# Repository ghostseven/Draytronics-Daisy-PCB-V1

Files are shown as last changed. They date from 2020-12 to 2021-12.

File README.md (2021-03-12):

# Draytronics-Daisy-PCB-V1

daisy  

An open source macro pad with rotary encoders and under glow, designed to be easily built with (mostly) through hole components. More info / kits / PCB designs available at https://www.draytronics.co.uk/daisy

\
daisypcb

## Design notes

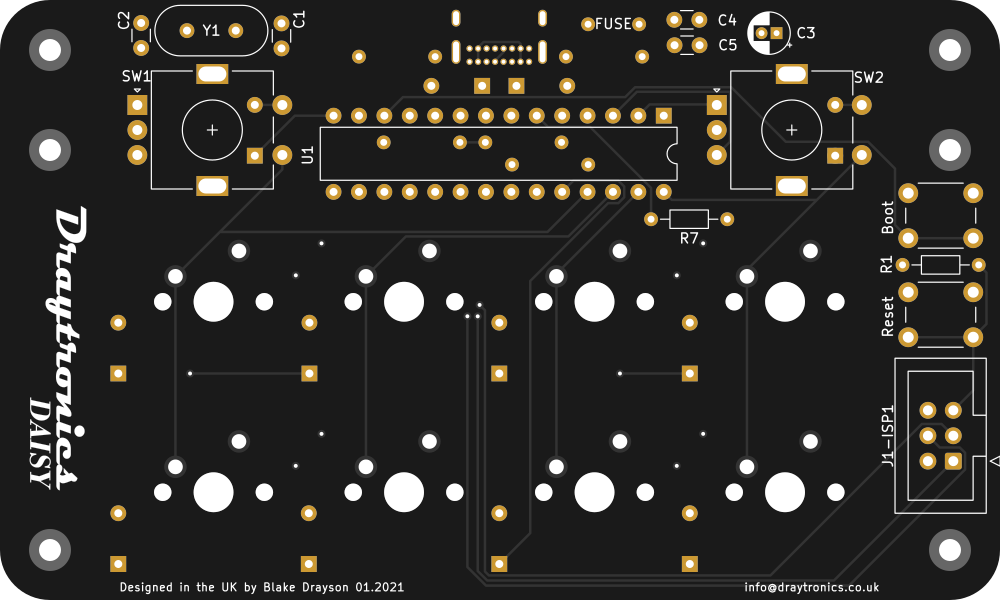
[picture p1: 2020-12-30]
Draytronics-Daisy-PCB-V1.png

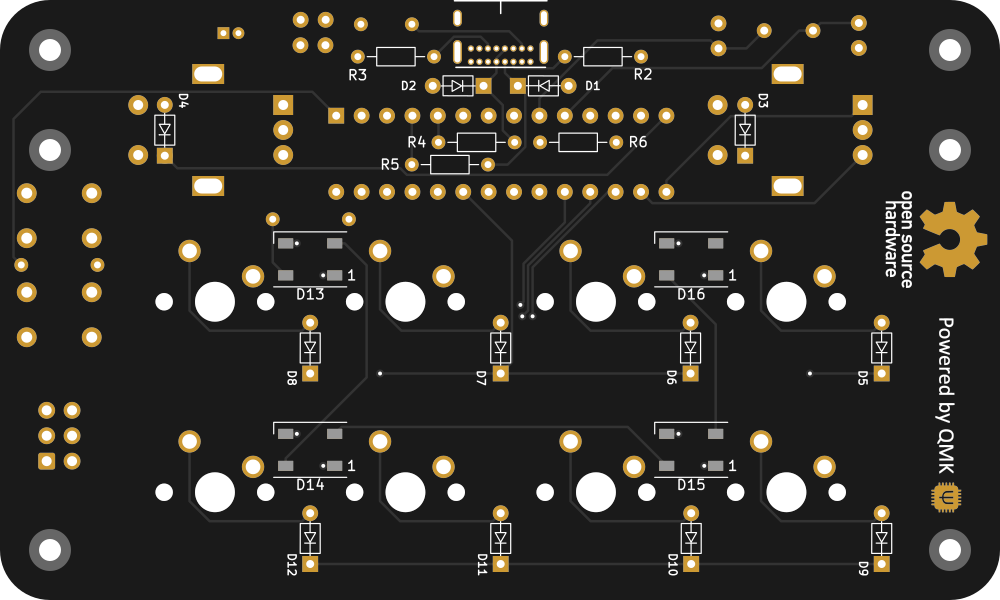
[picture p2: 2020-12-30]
Draytronics-Daisy-PCB-V1-bottom.png

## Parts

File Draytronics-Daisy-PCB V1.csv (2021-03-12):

Reference | Quantity | Value | Footprint | Datasheet
C1 C2 | 2 | 22pF | Capacitor_THT:C_Disc_D3.0mm_W1.6mm_P2.50mm | ~
C3 | 1 | 4.7uF | Capacitor_THT:CP_Radial_D4.0mm_P1.50mm | ~
C4 C5 | 2 | .1uF | Capacitor_THT:C_Disc_D3.0mm_W1.6mm_P2.50mm | ~
D13 D14 D15 D16 | 4 | WS2812B | LED_SMD:LED_WS2812B_PLCC4_5.0x5.0mm_P3.2mm | https://cdn-shop.adafruit.com/datasheets/WS2812B.pdf
D1 D2 | 2 | 3.6V | di-parts:D_DO-35_SOD27_P5.08mm_Horizontal | ~
D3 D4 D5 D6 D7 D8 D9 D10 D11 D12 | 10 | 1N4448W | di-parts:D_DO-35_SOD27_P5.08mm_Horizontal | https://www.vishay.com/docs/85722/1n4448w.pdf
F1 | 1 | 500ma | ctf-parts:polyfuse_5.1mm | ~
J1-ISP1 | 1 | AVR-ISP-6 | Connector_IDC:IDC-Header_2x03_P2.54mm_Vertical | ~
MX1 MX2 MX3 MX4 MX5 MX6 MX7 MX8 | 8 | MX-NoLED | MX_Only:MXOnly-1U-NoLED
R1 | 1 | 10k | Resistor_THT:R_Axial_DIN0204_L3.6mm_D1.6mm_P7.62mm_Horizontal | ~
R2 R3 | 2 | 5.1k | Resistor_THT:R_Axial_DIN0204_L3.6mm_D1.6mm_P7.62mm_Horizontal | ~
R4 R5 | 2 | 68R | Resistor_THT:R_Axial_DIN0204_L3.6mm_D1.6mm_P7.62mm_Horizontal | ~
R6 | 1 | 1.5k | Resistor_THT:R_Axial_DIN0204_L3.6mm_D1.6mm_P7.62mm_Horizontal | ~
R7 | 1 | 470R | Resistor_THT:R_Axial_DIN0204_L3.6mm_D1.6mm_P7.62mm_Horizontal | ~
SW1 SW2 | 2 | Rotary_Encoder_Switch | Rotary_Encoder:RotaryEncoder_Alps_EC11E-Switch_Vertical_H20mm | ~
SW3 | 1 | Reset | Button_Switch_THT:SW_PUSH_6mm
SW4 | 1 | Boot | Button_Switch_THT:SW_PUSH_6mm
U1 | 1 | ATmega328P-PU | Package_DIP:DIP-28_W7.62mm | http://ww1.microchip.com/downloads/en/DeviceDoc/ATmega328_P%20AVR%20MCU%20with%20picoPower%20Technology%20Data%20Sheet%2040001984A.pdf
USB1 | 1 | USB_C_Receptacle_USB2.0 | Type-C:USB_C_GCT_USB4085 | https://www.usb.org/sites/default/files/documents/usb_type-c.zip
Y1 | 1 | 16Mhz | Crystal:Crystal_HC49-U_Vertical | ~

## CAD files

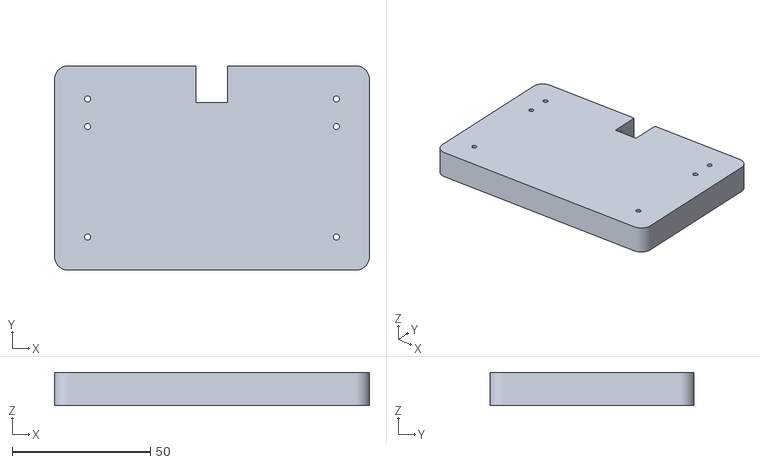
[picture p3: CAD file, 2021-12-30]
3d-printer-files/Draytronics-Daisy-PCB V1 - High Profile Case v1.stl
114.0 x 74.0 x 12.0

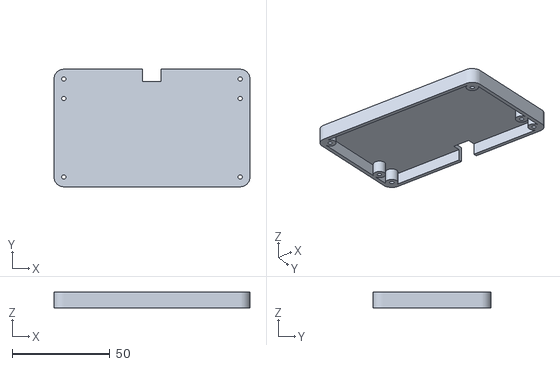
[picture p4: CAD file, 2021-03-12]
3d-printer-files/Draytronics-Daisy-PCB V1 - Bottom Case v6.stl
100.0 x 60.0 x 8.00

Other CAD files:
3d-printer-files/Draytronics-Daisy-PCB V1 - Bottom Case v6.f3d
3d-printer-files/Draytronics-Daisy-PCB V1 - High Profile Case v1.f3d

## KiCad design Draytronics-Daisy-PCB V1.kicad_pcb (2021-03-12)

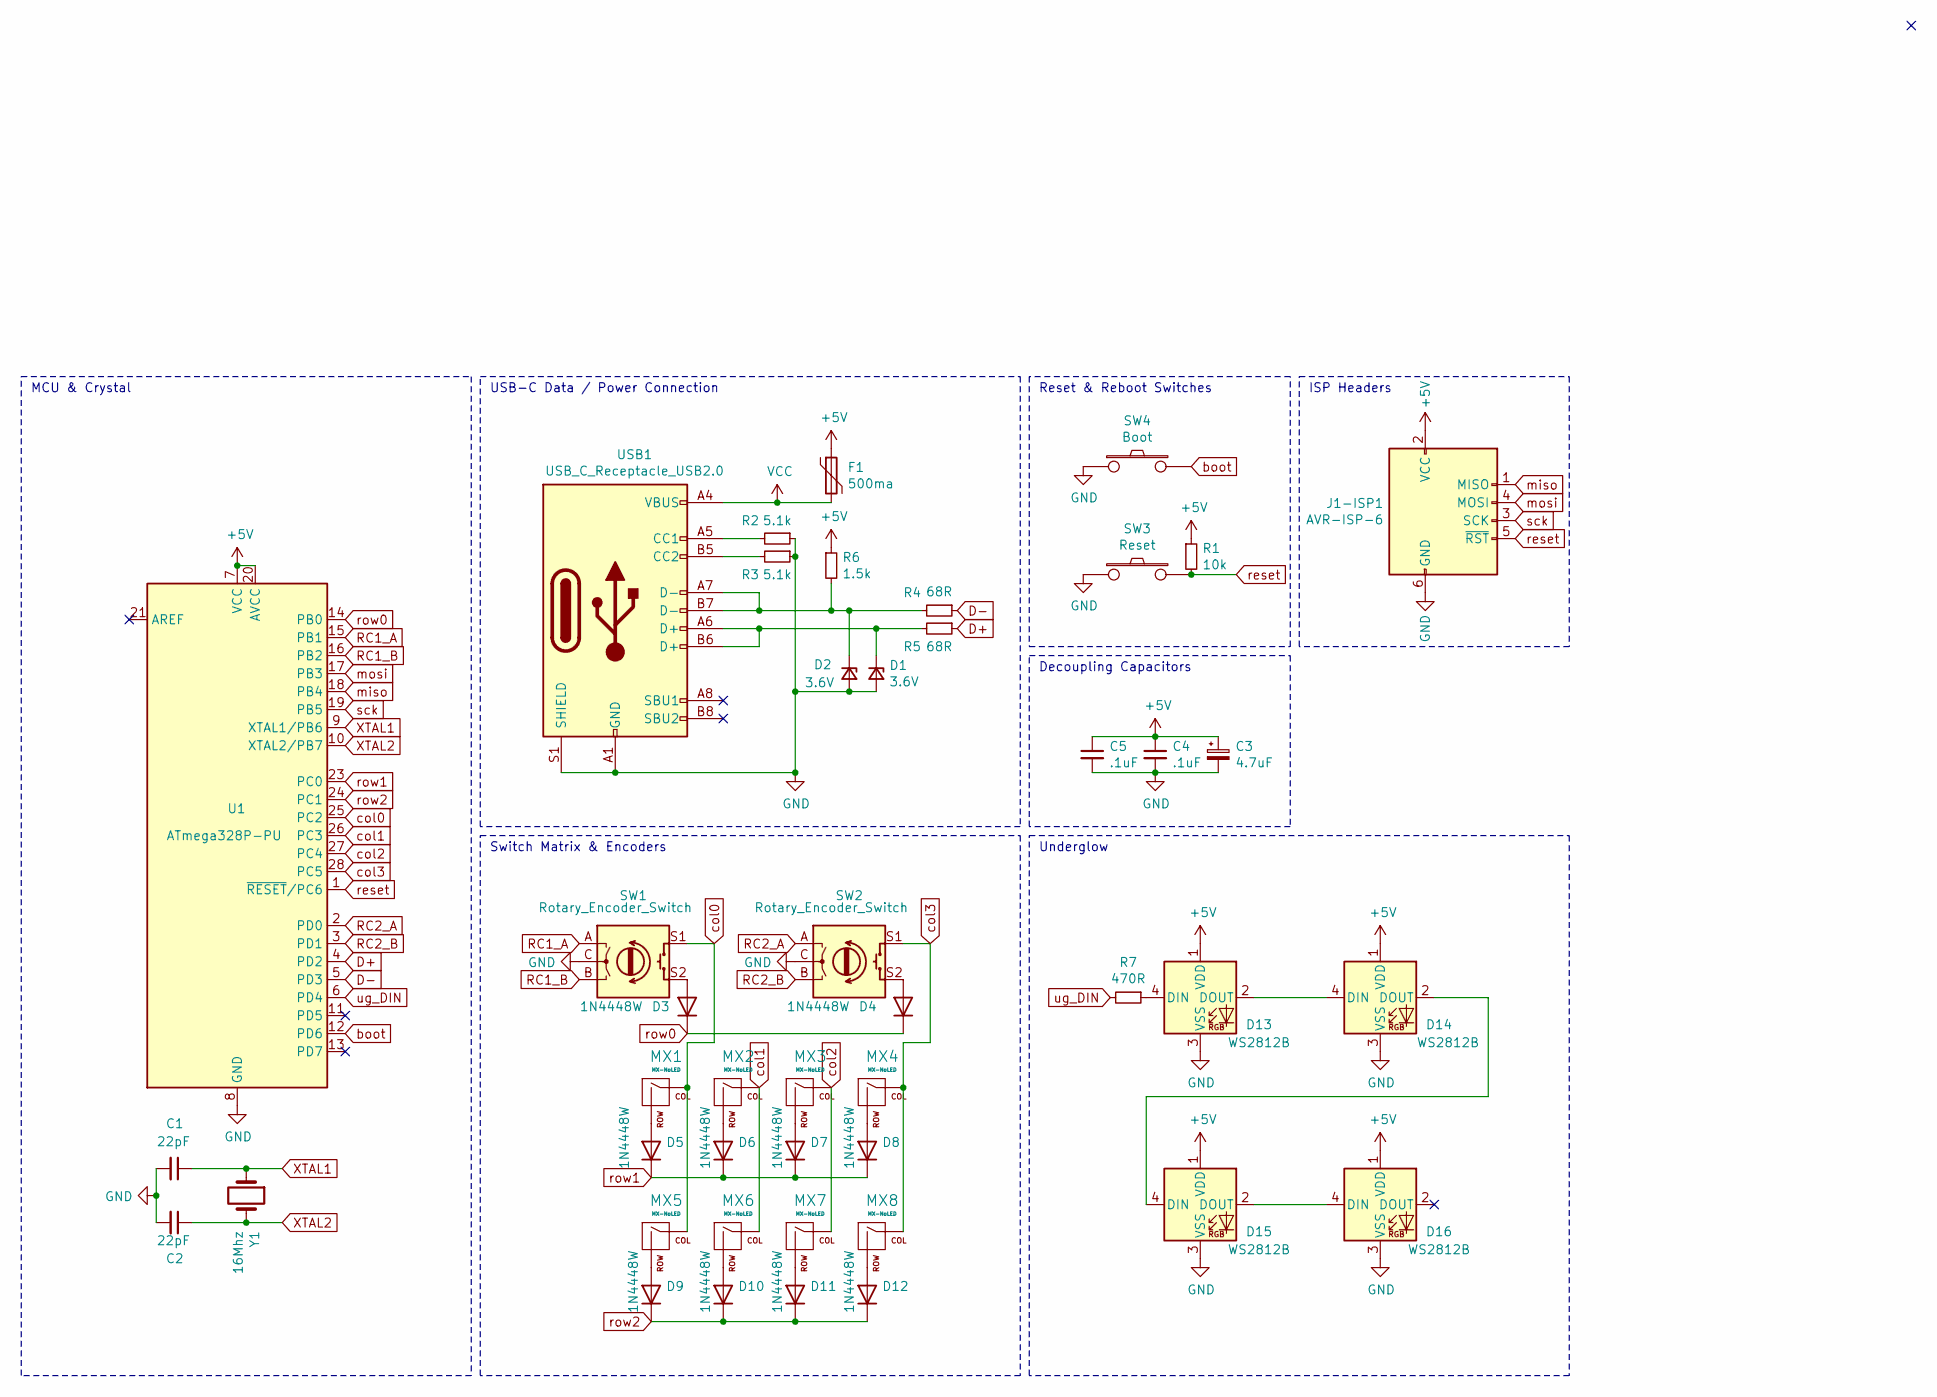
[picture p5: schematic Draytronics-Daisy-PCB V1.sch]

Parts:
C1, C2: 22pF; C_Disc_D3.0mm_W1.6mm_P2.50mm
C3: 4.7uF; CP_Radial_D4.0mm_P1.50mm
C4, C5: .1uF; C_Disc_D3.0mm_W1.6mm_P2.50mm
D1, D2: 3.6V; D_DO-35_SOD27_P5.08mm_Horizontal
D3, D4, D5, D6, D7, D8, D9, D10, D11, D12: 1N4448W; D_DO-35_SOD27_P5.08mm_Horizontal
D13, D14, D15, D16: WS2812B; LED_WS2812B_PLCC4_5.0x5.0mm_P3.2mm
F1: 500ma; polyfuse_5.1mm
J1-ISP1: AVR-ISP-6; IDC-Header_2x03_P2.54mm_Vertical
MX1, MX2, MX3, MX4, MX5, MX6, MX7, MX8: MX-NoLED; MXOnly-1U-NoLED
R1: 10k; R_Axial_DIN0204_L3.6mm_D1.6mm_P7.62mm_Horizontal
R2, R3: 5.1k; R_Axial_DIN0204_L3.6mm_D1.6mm_P7.62mm_Horizontal
R4, R5: 68R; R_Axial_DIN0204_L3.6mm_D1.6mm_P7.62mm_Horizontal
R6: 1.5k; R_Axial_DIN0204_L3.6mm_D1.6mm_P7.62mm_Horizontal
R7: 470R; R_Axial_DIN0204_L3.6mm_D1.6mm_P7.62mm_Horizontal
SW1, SW2: Rotary_Encoder_Switch; RotaryEncoder_Alps_EC11E-Switch_Vertical_H20mm
SW3: Reset; SW_PUSH_6mm
SW4: Boot; SW_PUSH_6mm
U1: ATmega328P-PU; DIP-28_W7.62mm
USB1: USB_C_Receptacle_USB2.0; USB_C_GCT_USB4085
Y1: 16Mhz; Crystal_HC49-U_Vertical

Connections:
+5V: C3.1, C4.1, C5.1, D13.1 (VDD), D14.1 (VDD), D15.1 (VDD), D16.1 (VDD), F1.1, J1-ISP1.2 (VCC), R1.1, R6.1, U1.7 (VCC), U1.20 (AVCC)
D+: R5.1, U1.4 (PD2)
D-: R4.1, U1.5 (PD3)
GND: C1.2, C2.2, C3.2, C4.2, C5.2, D1.2 (A), D2.2 (A), D13.3 (VSS), D14.3 (VSS), D15.3 (VSS), D16.3 (VSS), J1-ISP1.6 (GND), R2.1, R3.1, SW1.C, SW2.C, SW3.1, SW4.1, U1.8 (GND), U1.22 (GND), USB1.A1 (GND), USB1.A12 (GND), USB1.B1 (GND), USB1.B12 (GND), USB1.S1 (SHIELD)
unnamed: D1.1 (K), R5.2, USB1.A6 (D+), USB1.B6 (D+)
unnamed: D2.1 (K), R4.2, R6.2, USB1.A7 (D-), USB1.B7 (D-)
unnamed: D3.2 (A), SW1.S2
unnamed: D4.2 (A), SW2.S2
unnamed: D5.2 (A), MX1.2 (ROW)
unnamed: D6.2 (A), MX2.2 (ROW)
unnamed: D7.2 (A), MX3.2 (ROW)
unnamed: D8.2 (A), MX4.2 (ROW)
unnamed: D9.2 (A), MX5.2 (ROW)
unnamed: D10.2 (A), MX6.2 (ROW)
unnamed: D11.2 (A), MX7.2 (ROW)
unnamed: D12.2 (A), MX8.2 (ROW)
unnamed: D13.2 (DOUT), D14.4 (DIN)
unnamed: D13.4 (DIN), R7.1
unnamed: D14.2 (DOUT), D15.4 (DIN)
unnamed: D15.2 (DOUT), D16.4 (DIN)
unnamed: R2.2, USB1.A5 (CC1)
unnamed: R3.2, USB1.B5 (CC2)
RC1_A: SW1.A, U1.15 (PB1)
RC1_B: SW1.B, U1.16 (PB2)
RC2_A: SW2.A, U1.2 (PD0)
RC2_B: SW2.B, U1.3 (PD1)
VCC: F1.2, USB1.A4 (VBUS), USB1.A9 (VBUS), USB1.B4 (VBUS), USB1.B9 (VBUS)
XTAL1: C1.1, U1.9 (XTAL1/PB6), Y1.1
XTAL2: C2.1, U1.10 (XTAL2/PB7), Y1.2
boot: SW4.2, U1.12 (PD6)
col0: MX1.1 (COL), MX5.1 (COL), SW1.S1, U1.25 (PC2)
col1: MX2.1 (COL), MX6.1 (COL), U1.26 (PC3)
col2: MX3.1 (COL), MX7.1 (COL), U1.27 (PC4)
col3: MX4.1 (COL), MX8.1 (COL), SW2.S1, U1.28 (PC5)
miso: J1-ISP1.1 (MISO), U1.18 (PB4)
mosi: J1-ISP1.4 (MOSI), U1.17 (PB3)
reset: J1-ISP1.5 (~RST), R1.2, SW3.2, U1.1 (~RESET~/PC6)
row0: D3.1 (K), D4.1 (K), U1.14 (PB0)
row1: D5.1 (K), D6.1 (K), D7.1 (K), D8.1 (K), U1.23 (PC0)
row2: D9.1 (K), D10.1 (K), D11.1 (K), D12.1 (K), U1.24 (PC1)
sck: J1-ISP1.3 (SCK), U1.19 (PB5)
ug_DIN: R7.2, U1.6 (PD4)

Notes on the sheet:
USB-C Data / Power Connection
MCU & Crystal
Reset & Reboot Switches
ISP Headers
Decoupling Capacitors
Switch Matrix & Encoders
Underglow

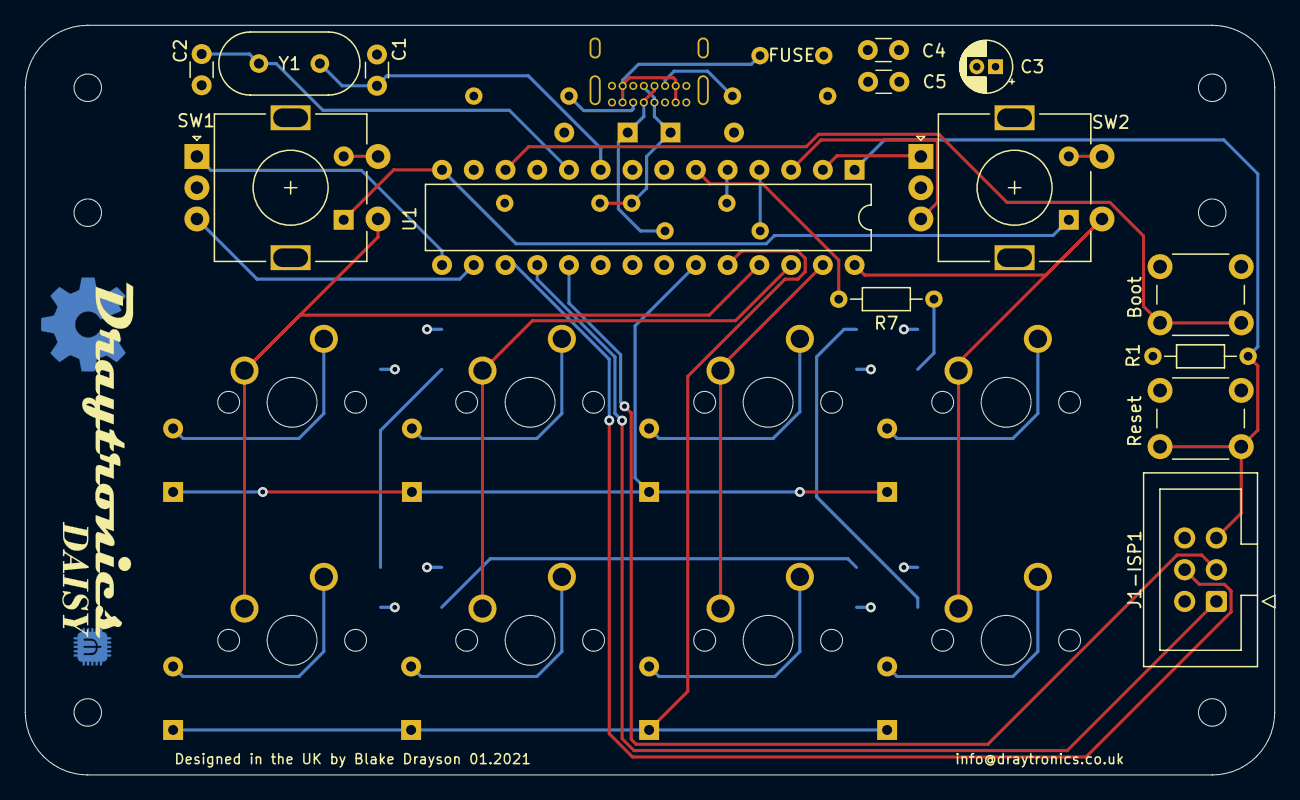
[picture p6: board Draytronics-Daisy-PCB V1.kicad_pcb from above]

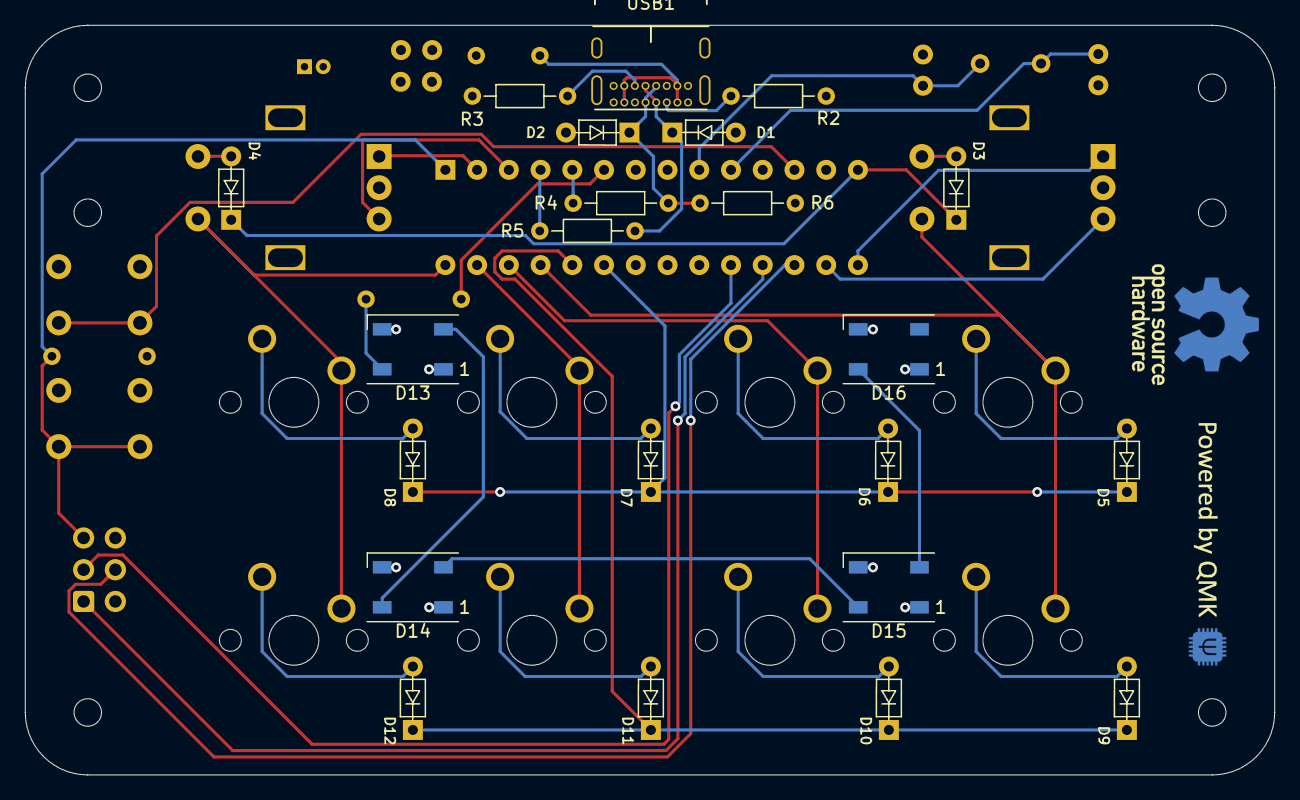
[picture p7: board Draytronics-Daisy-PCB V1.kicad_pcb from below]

Board: 4 copper layers, 100.0 x 60.0 mm, 45 parts (22 on the bottom side), 42 nets.

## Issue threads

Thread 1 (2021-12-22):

Bootloader

dayofdoom, 2021-12-22:
Hello,

Is there a custom bootloader for this or is it the standard one for the chip?

Thank you

ghostseven, 2021-12-23:
Ah crap yes I have not written the guide to flashing this yet sorry about that.  It uses a a modified version of USBaspLoader.  The change is basically just adjustment of D+, D- pins to match QMK standards.

If you grab the fork here - https://github.com/ghostseven/USBaspLoader

You will need to make a tweak to the Makefile.inc to change

DEVICE = atmega328p

FLASHADDRESS = 0x7000

As the default is setup for flashing my Scarlet Keyboard that has a ATMega32 chip.

You can then basically follow the flashing guide here - https://www.draytronics.co.uk/scarlet-firmware-programming-guide/

You will need to change out the QMK firmware so you flash the Daisy firmware instead of Scarlet.

Sorry I would write up a full guide but my lab is currently packed in boxes waiting for a house move!

Any problems drop me a message and I will do my best to help.

dayofdoom, 2021-12-23:
This is perfect, thanks for the information! I'm working on a high profile 3D case too - using the files you provided in the repo.

ghostseven, 2021-12-23:
No problem at all, sorry I have not got something more formal together.  I kind of got stuck with chip shortages and other things so I never made up kits, otherwise I would have fully documented it.   The high profile case sounds great, I would love to see how that turns out.  I hope you have a lovely Xmas.

dayofdoom, 2021-12-30:
So I went ahead and edit the makefile.inc like you wrote above and changed my programmer to USBASP to match my environment. When I run `make firmware`, this is what I get `!!!ATTANTION!!!
(data+text) MUST fit into your MCUs bootloader section
.
   text	   data	    bss	    dec	    hex	filename
   2164	      6	     55	   2225	    8b1	main.el`

Any suggestions?

ghostseven, 2021-12-30:
Hmm, right I am finding the packing box with my boot loader programmer and I will have a play!

Thanks

Blake
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

ghostseven, 2021-12-30:
Sorry I am being dumb today, that is actually just a warning message.   It should not cause you any problems.

I just managed to dig out my programmer and flash the daisy pcb from scratch with it.  It all works fine, you will get the ‘flash fuse’ complaining but you can ignore that.

Ping me back if you have issues but you can ignore that error about the MCUs bootloader section.  I even have a picture of it doing that on the Scarlet flashing guide here : https://www.draytronics.co.uk/scarlet-firmware-programming-guide/

Thanks

Blake
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

dayofdoom, 2021-12-30:
I was dumb too and found that in the documentation as well. All good. Still having trouble getting the make fuse to work correctly.

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

ghostseven, 2021-12-31:
You will be ok with those fuse settings, it did the same to me. I need to poke around and check (I think it is trying to set a fuse that it is not possible to change) but that will work now and allow you to flash the qmk firmware.

Thanks

Blake
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

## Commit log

2020-12-30 Added PCB renders
2021-03-12 First prod version
    [Draytronics-Daisy-PCB V1 - Bottom Case v6.f3d, Draytronics-Daisy-PCB V1 - Bottom Case v6.stl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]
2021-12-30 added high profile case
    added .f3d and .stl of high profile case based off the original one released
    [Draytronics-Daisy-PCB V1 - High Profile Case v1.f3d, Draytronics-Daisy-PCB V1 - High Profile Case v1.stl]
